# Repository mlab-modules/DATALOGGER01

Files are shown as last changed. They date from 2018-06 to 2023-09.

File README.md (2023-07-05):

# DATALOGGER01 - MLAB's Versatile processor module

The DATALOGGER01 is a versatile electronic module designed by MLAB, containing an ATmega1284p processor. The module is programmable in the Arduino IDE and compatible with a variety of development environments and programming languages.

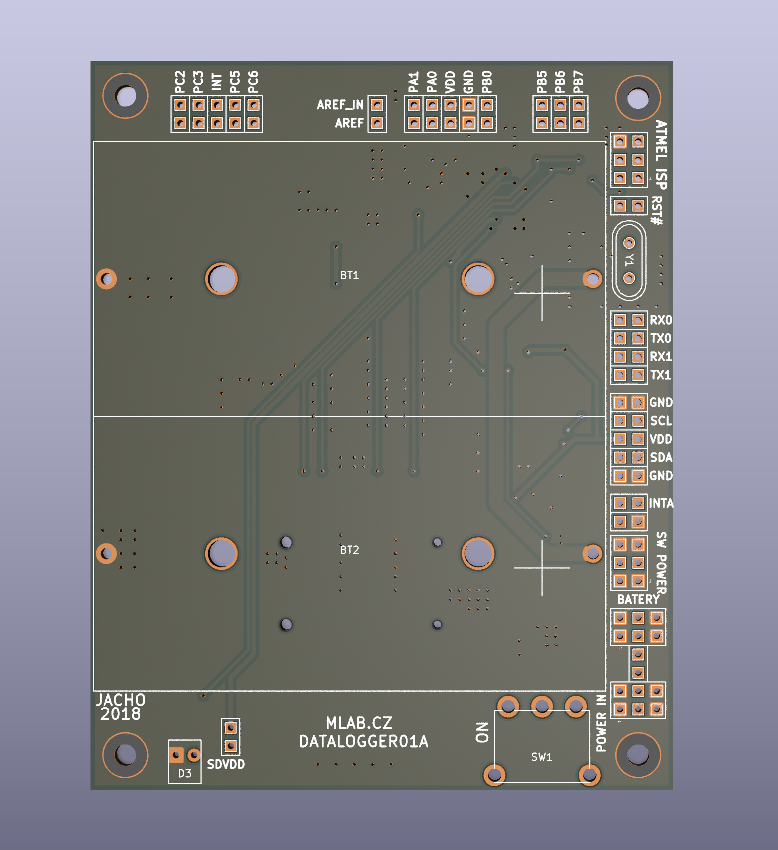
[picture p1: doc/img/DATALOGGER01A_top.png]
DATALOGGER01A
 

One of the significant features of this module is an SD card slot, a convenient provision for data logging from the processor. With a built-in battery holder, the module ensures uninterrupted operation without reliance on an external power supply.

The DATALOGGER01 exhibits a range of applications, thanks to its I2C, UART, ADC input, and GPIO pins. Additionally, it's furnished with a power switch to effectively manage power consumption of connected devices.

Setting it apart, the module includes an EEPROM AT23CS64, containing a unique serial number to distinguish logs from different DATALOGGER01-based devices. Moreover, it comprises a PCF85263 RTC circuit, with the option to connect a backup battery.

## Key Features:
- **Processor:** [ATmega1284p](https://en.wikipedia.org/wiki/Atmel_AVR#ATmega)
- **Interoperability:** Compatibility with Arduino and supports a range of other development platforms and programming languages.
- **Data Logging:** An SD Card Slot for extensive data storage.
- **Power Management:** Self-sufficient with an integrated battery holder.
- **Connectivity Options:** Diverse interfacing options with I2C, UART, ADC input, and GPIO pins.
- **Energy Efficiency:** Onboard power switch for managing external devices' power consumption.
- **Unique Identification:** Inbuilt [EEPROM AT23CS64](https://www.mouser.com/datasheet/2/268/doc0180-1353557.pdf) with a unique serial number.
- **Real-Time Tracking:** Inclusion of a [PCF85263](https://www.nxp.com/docs/en/data-sheet/PCF85263A.pdf) RTC circuit with backup battery connectivity.

## Potential Use Cases:
- **Data Collection:** Can collect, store, and analyze data from various sensors and devices.
- **Remote Monitoring:** Can be incorporated into IoT systems for remote data collection and monitoring.
- **Autonomous Systems:** Suitable for devices needing independent functioning.
- **Space Research:** Applicable as data loggers and locator devices for stratospheric balloons.

## In Action:
- The DATALOGGER01 module has proven its efficacy in:
   - **[GEODOS01](https://www.ust.cz/UST-dosimeters/GEODOS/)**: A fully autonomous scintillation detector incorporating LoRa IoT, operating without human intervention.
   - **FÍK stratospherics balloons Avionics**: DATALOGGER1 played a important role as a data logger and locator in the stratospheric balloons' avionics organized by [ODZ ÚJF](http://www.ujf.cas.cz/cs/oddeleni/oddeleni-dozimetrie-zareni/vyzkum/lety-fik/).

## Schematics



## Useful Links:
- [ATmega1284p](https://en.wikipedia.org/wiki/Atmel_AVR#ATmega) - Wikipedia
- [ARDUINO Programming Environment](https://www.arduino.cc/) - Official Arduino Site
- [EEPROM AT23CS64](https://www.mouser.com/datasheet/2/268/doc0180-1353557.pdf) - Mouser Electronics
- [PCF85263](https://www.nxp.com/docs/en/data-sheet/PCF85263A.pdf) - NXP Semiconductors

Discover the potential of DATALOGGER01 module and utilize it for your projects!

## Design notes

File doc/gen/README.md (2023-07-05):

# PCB

Board size: 80.77x101.09 mm (3.18x3.98 inches)

- This is the size of the rectangle that contains the board
- Thickness: 1.6 mm (63 mils)
- Material: FR4
- Finish: HAL
- Layers: 2
- Copper thickness: 35 µm

Solder mask: TOP / BOTTOM

- Color: Green

Silk screen: TOP / BOTTOM

- Color: White

# Important sizes

Clearance: 0.2 mm (8 mils)

Track width: 0.25 mm (10 mils)

- By design rules: 0.2 mm (8 mils)

Drill: 0.35 mm (14 mils)

- Vias: 0.5 mm (20 mils) [Design: 0.5 mm (20 mils)]
- Pads: 0.35 mm (14 mils)
- The above values are real drill sizes, they add 0.1 mm (4 mils) to plated holes (PTH)

Via: 0.8/0.4 mm (31/16 mils)

- By design rules: 0.8/0.4 mm (31/16 mils)
- Micro via: yes [0.2/0.1 mm (8/4 mils)]
- Buried/blind via: yes
- Total: 220 (thru: 220 buried/blind: 0 micro: 0)

Outer Annular Ring: 0.13 mm (5 mils)

- By design rules: 0.13 mm (5 mils)

Eurocircuits class: 6C
- Using min drill 0.35 mm for an OAR of 0.13 mm

# General stats

Components count: (SMD/THT)

- Top: 0/40 (THT)
- Bottom: 47/3 (SMD + THT)

Defined tracks:

- 0.25 mm (10 mils)
- 0.3 mm (12 mils)
- 0.4 mm (16 mils)
- 0.5 mm (20 mils)
- 0.6 mm (24 mils)
- 1.0 mm (39 mils)
- 2.0 mm (79 mils)

Used tracks:

- 0.25 mm (10 mils) (57) defined: yes
- 0.3 mm (12 mils) (233) defined: yes
- 0.4 mm (16 mils) (363) defined: yes
- 0.6 mm (24 mils) (67) defined: yes
- 2.0 mm (79 mils) (38) defined: yes

Defined vias:

- 0.8/0.4 mm (31/16 mils)

Used vias:

- 0.8/0.4 mm (31/16 mils) (Count: 220, Aspect: 2.0 A) defined: yes

Holes (excluding vias):

- 0.25 mm (10 mils) (2)
- 0.8 mm (32 mils) (2)
- 0.89 mm (35 mils) (80)
- 0.9 mm (35 mils) (2)
- 1.1 mm (43 mils) (2)
- 1.6 mm (63 mils) (6)
- 1.85 mm (73 mils) (5)
- 3.0 mm (118 mils) (3)
- 3.8 mm (150 mils) (4)

Oval holes:

Drill tools (including vias and computing adjusts and rounding):

- 0.35 mm (14 mils) (2)
- 0.5 mm (20 mils) (220)
- 0.9 mm (35 mils) (2)
- 1.0 mm (39 mils) (82)
- 1.1 mm (43 mils) (2)
- 1.6 mm (63 mils) (2)
- 1.7 mm (67 mils) (4)
- 1.95 mm (77 mils) (5)
- 3.1 mm (122 mils) (3)
- 3.8 mm (150 mils) (4)

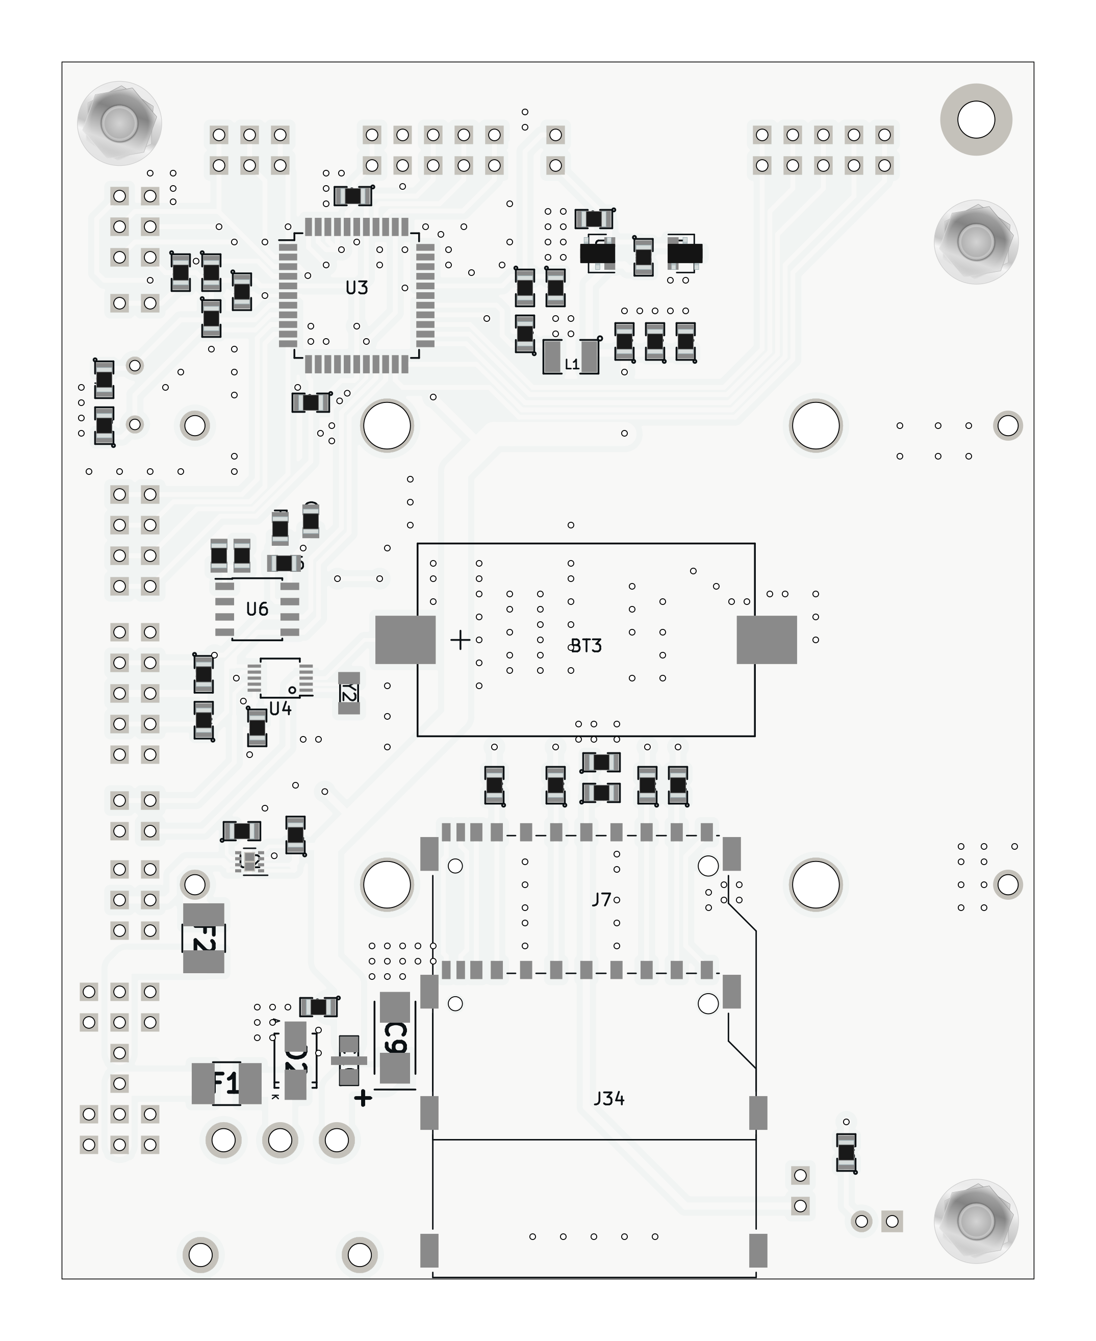
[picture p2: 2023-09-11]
doc/gen/img/DATALOGGER01-bottom.png

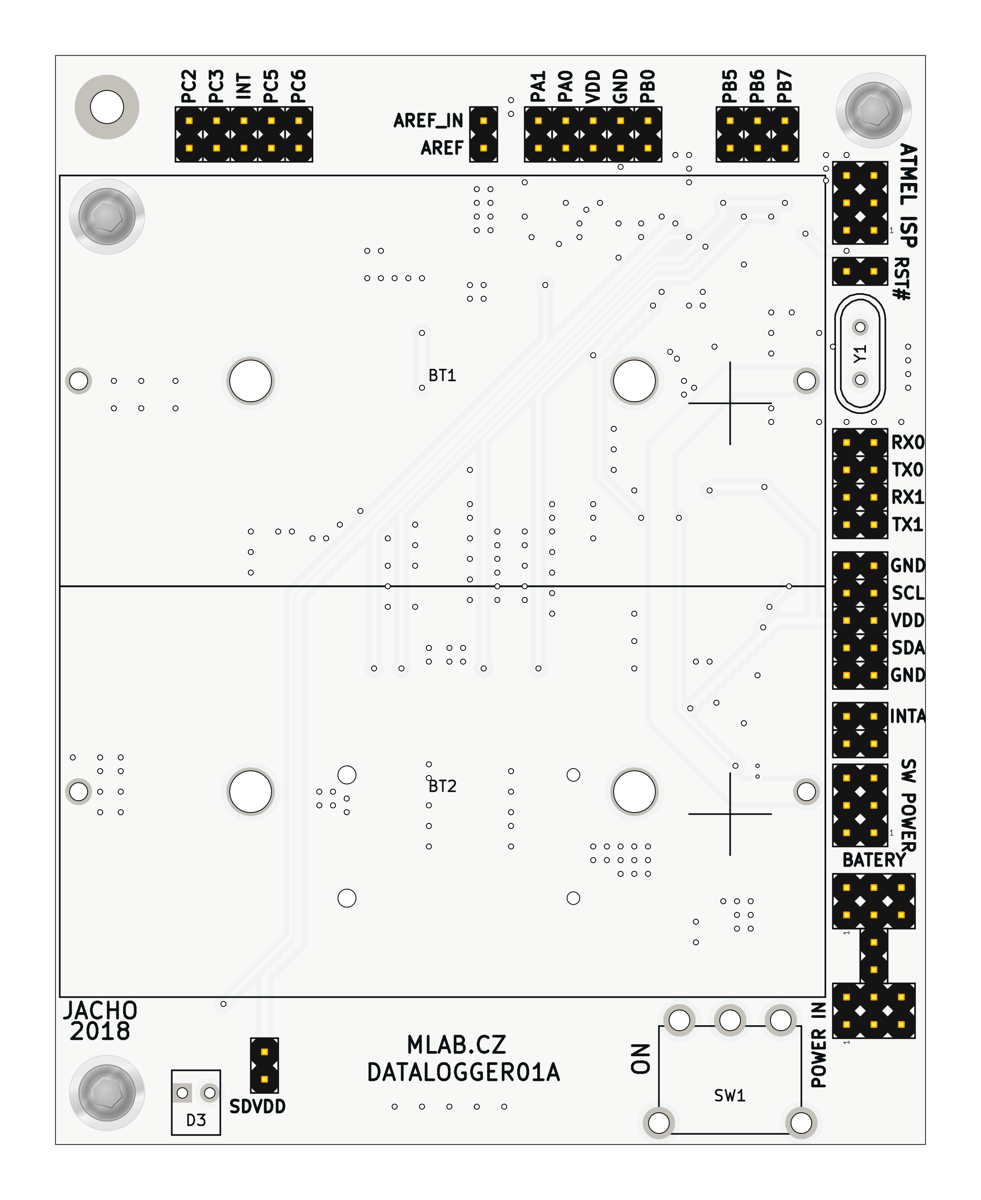
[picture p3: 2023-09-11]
doc/gen/img/DATALOGGER01-top.png

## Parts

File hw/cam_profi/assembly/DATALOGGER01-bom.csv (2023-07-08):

Component | Description | Part | References | Value | Footprint | Quantity Per PCB | Datasheet | ust_id
1 |  | Battery_Cell-device | BT1BT2 | BX0037 | BX0037 | 2 |  | 5c70984412875079b91f87ed
2 |  | Battery_Cell-device | BT3 | Battery_Cell-device | CH28-2032 | 1 |  | 5c70984412875079b91f87ec
3 |  | C-device | C5C8 | 15pF | SMD-0805 | 2 |  | 5c70984712875079b91f8b32
4 |  | C-device | C12 | 1nF | SMD-0805 | 1 |  | 5c70984712875079b91f8b45
5 |  | C-device | C1C2C3C4C6C13C15C17C18C19C20C21C22 | 100nF | SMD-0805 | 13 |  | 5c70984712875079b91f8b4c
6 |  | C-device | C7 | 1uF | SMD-0805 | 1 |  | 5c70984712875079b91f8b50
7 |  | C-device | C16 | 4u7 | SMD-0805 | 1 |  | 5c70984712875079b91f8b52
8 |  | C-device | C11C14 | 10uF | SMD-0805 | 2 |  | 5c70984812875079b91f8bbd
9 |  | CP-device | C9 | 47uF | TantalC_SizeC_Reflow | 1 |  | 5c70984412875079b91f8867
10 |  | EMI_Filter_C-device | C10 | EMI_Filter_C | FIR1 | 1 | http://www.murata.com/~/media/webrenewal/support/library/catalog/products/emc/emifil/c31e.ashx?la=en-gb
11 |  | LED-device | D3 | HLMP-K150+FIX-LED-313 | FIX-LED-313 | 1 |  | 5c70984712875079b91f8b67
12 |  | D-device | D2 | M4 | SMA_Standard | 1 |  | 5c70984512875079b91f88ac
13 |  | Polyfuse-device | F1F2 | 750mA | 1812 | 2 |  | 5c70984512875079b91f88d2
14 |  | HEADER_2x01-MLAB_HEADER | J9J11J21J32 | HEADER_2x01 | Straight_2x01 | 4
15 |  | HEADER_2x01_PARALLEL-MLAB_HEADER | J1J2J3J4J5J8J12J13J14J15J16J17J18J19J20J22J23J24J25J26J27J28J29J30 | HEADER_2x01_PARALLEL | Straight_2x01 | 24
16 |  | HEADER_2x03-MLAB_HEADER | J31 | HEADER_2x03 | Straight_2x03 | 1
17 |  | HEADER_2x03_PARALLEL-MLAB_HEADER | J6J10J33 | HEADER_2x03_PARALLEL | Straight_2x03 | 3
18 |  | SD_Card-Connector | J7 | MCC-SD | SD_TE_2041021 | 1 | http://portal.fciconnect.com/Comergent//fci/drawing/10067847.pdf | 5c70984412875079b91f87f2
19 |  | SD_Card-Connector | J34 | MCC-SD (kouka z modulu) | MCC-SD | 1 | http://portal.fciconnect.com/Comergent//fci/drawing/10067847.pdf
20 |  | L-device | L1 | 10uH - LQH32CN100K23L | SMD-1210 | 1 |  | 5c70984412875079b91f87ff
21 |  | R-device | R12R15 | 0R | SMD-0805 | 2 |  | 5c70984512875079b91f896b
22 |  | R-device | R1R2R3R4 | 100 | SMD-0805 | 4 |  | 5c70984512875079b91f8977
23 |  | R-device | R10 | 2k2 | SMD-0805 | 1 |  | 5c70984612875079b91f8990
24 |  | R-device | R5 | 4k7 | SMD-0805 | 1 |  | 5c70984612875079b91f8995
25 |  | R-device | R6R7R9 | 10k | SMD-0805 | 3 |  | 5c70984612875079b91f899f
26 |  | R-device | R8R11R16 | - | SMD-0805 | 3
27 | Single Pole Single Throw (SPST) switch | SW_SPST | SW1 | 5MS1S102AM6QE | 5MS1S102AM6QE | 1 | ~ | 5c70984712875079b91f8b66
28 | I2C Serial EEPROM, 64Kb (8192x8) with Unique Serial Number, SO8 | AT24CS64-SSHM | U6 | AT24CS64-SSHM | SOIC-8_3.9x4.9mm_P1.27mm | 1 | http://ww1.microchip.com/downloads/en/DeviceDoc/Atmel-8870-SEEPROM-AT24CS64-Datasheet.pdf | 5c70984712875079b91f8b99
29 |  | ATMEGA1284P-AU-atmel | U3 | ATMEGA1284P-AU | TQFP-44_10x10mm_P0.8mm | 1 | http://www.atmel.com/Images/Atmel-8272-8-bit-AVR-microcontroller-ATmega164A_PA-324A_PA-644A_PA-1284_P_datasheet.pdf | 5c70984412875079b91f888e
30 |  | ISL21070CIH320Z-TK-references | U1 | ISL21080CIH320Z-TK | SOT-23 | 1 | http://www.intersil.com/content/dam/Intersil/documents/fn75/fn7599.pdf | 5c70984712875079b91f8b79
31 |  | LM4041CIM3-1.2-MLAB_D | U5 | LM4041CIM3-1.2(neosazovat) | SOT-23 | 1
32 |  | PCF85263A-MLAB_IO | U4 | PCF85263A | TSSOP-10_3x3mm_Pitch0.5mm | 1 |  | 5c70984612875079b91f8a0c
33 |  | TPS22965-Q1-MLAB_IO | U2 | TPS22965-Q1 | WSON-8-1EP_2x2mm_P0.5mm_EP0.9x1.6mm_ThermalVias | 1 |  | 5c70984712875079b91f8b78
34 | Two pin crystal | Crystal | Y1 | 16MHz | Crystal_HC49-U_Vertical | 1 | ~ | 5c70984712875079b91f8b10
35 |  | Crystal-device | Y2 | ABS07-120-32.768KHZ-T | ABS07 | 1 |  | 5c70984712875079b91f8b1b

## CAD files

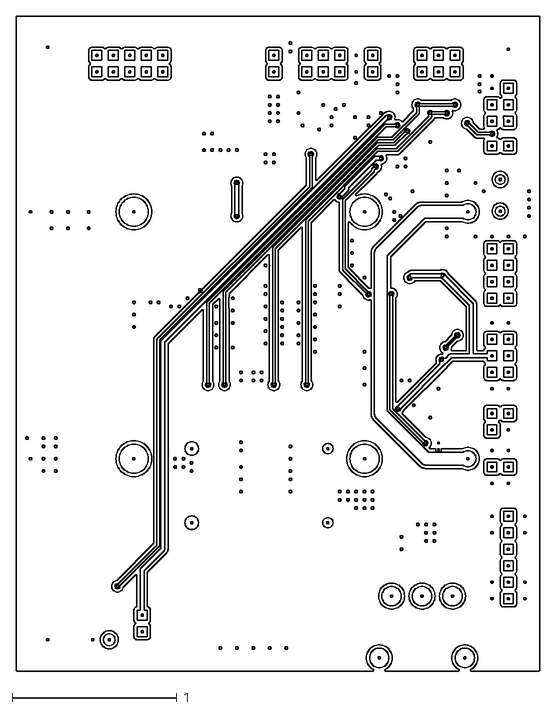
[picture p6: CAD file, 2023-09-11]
doc/gen/dxf/DATALOGGER01-F_Cu.dxf
3.18 x 3.98

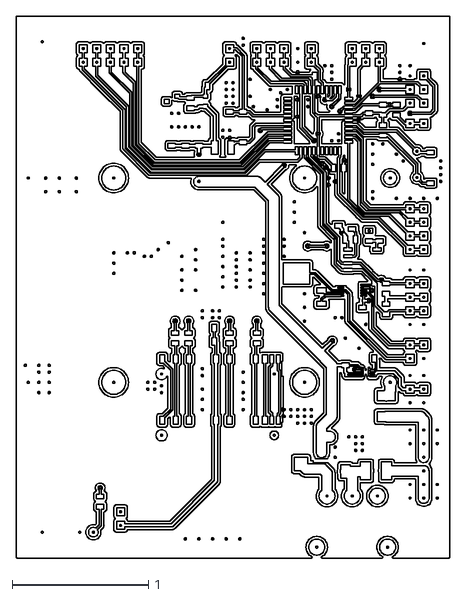
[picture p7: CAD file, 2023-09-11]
doc/gen/dxf/DATALOGGER01-B_Cu.dxf
3.18 x 3.98

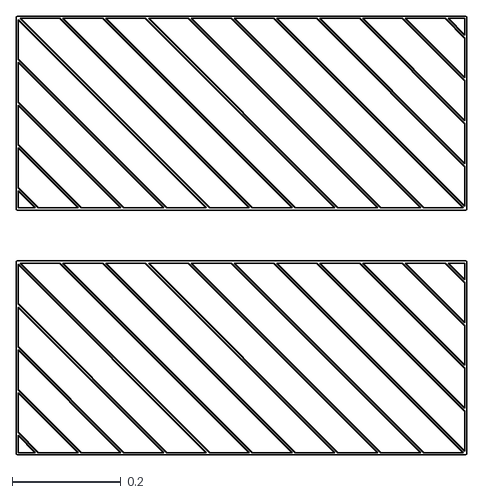
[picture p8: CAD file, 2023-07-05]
doc/gen/dxf/DATALOGGER01-User_Drawings.dxf
0.83 x 0.806

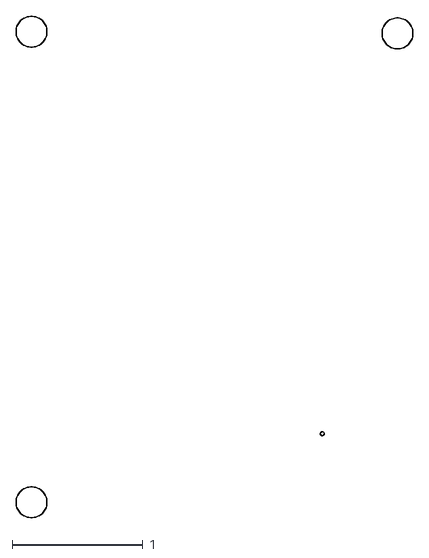
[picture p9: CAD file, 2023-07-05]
doc/gen/dxf/DATALOGGER01-B_Adhesive.dxf
3.04 x 3.84

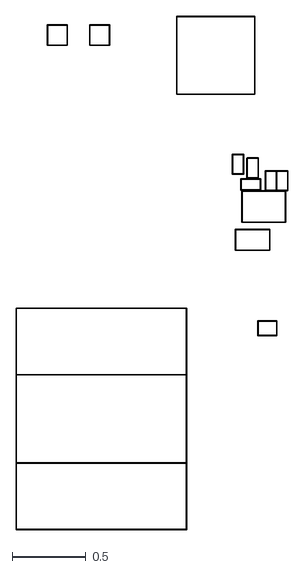
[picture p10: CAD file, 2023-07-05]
doc/gen/dxf/DATALOGGER01-B_Courtyard.dxf
1.84 x 3.48

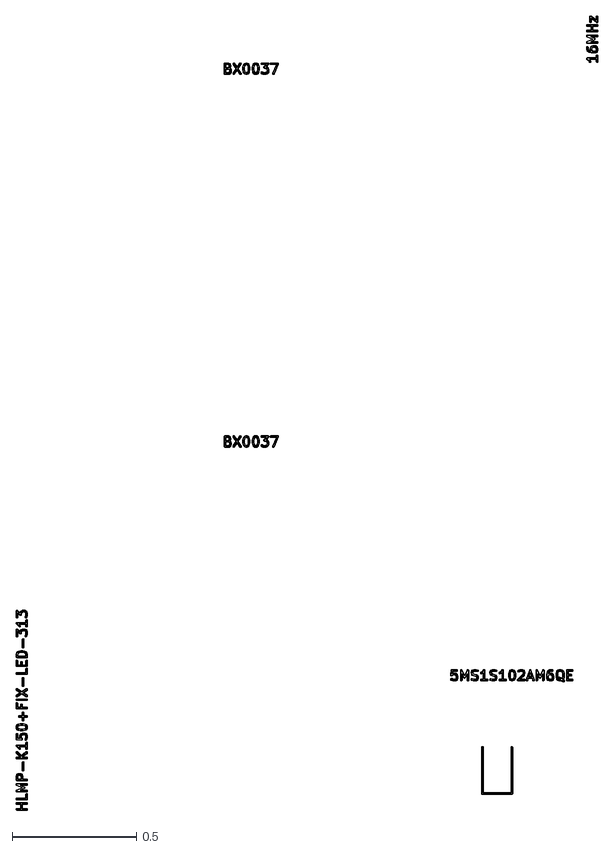
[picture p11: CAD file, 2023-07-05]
doc/gen/dxf/DATALOGGER01-F_Fab.dxf
2.34 x 3.19

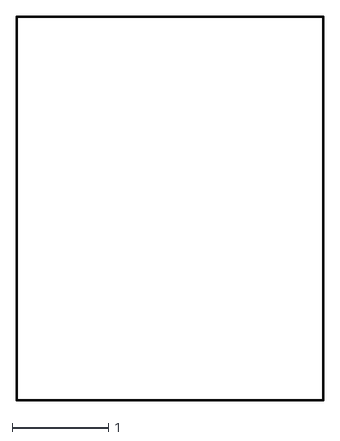
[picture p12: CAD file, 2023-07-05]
doc/gen/dxf/DATALOGGER01-Edge_Cuts.dxf
3.19 x 3.99

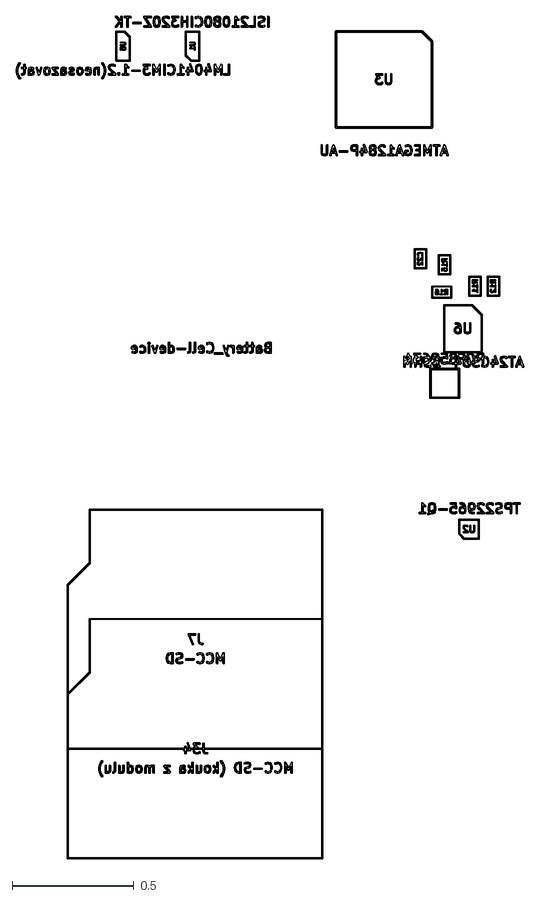
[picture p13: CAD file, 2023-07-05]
doc/gen/dxf/DATALOGGER01-B_Fab.dxf
2.09 x 3.47

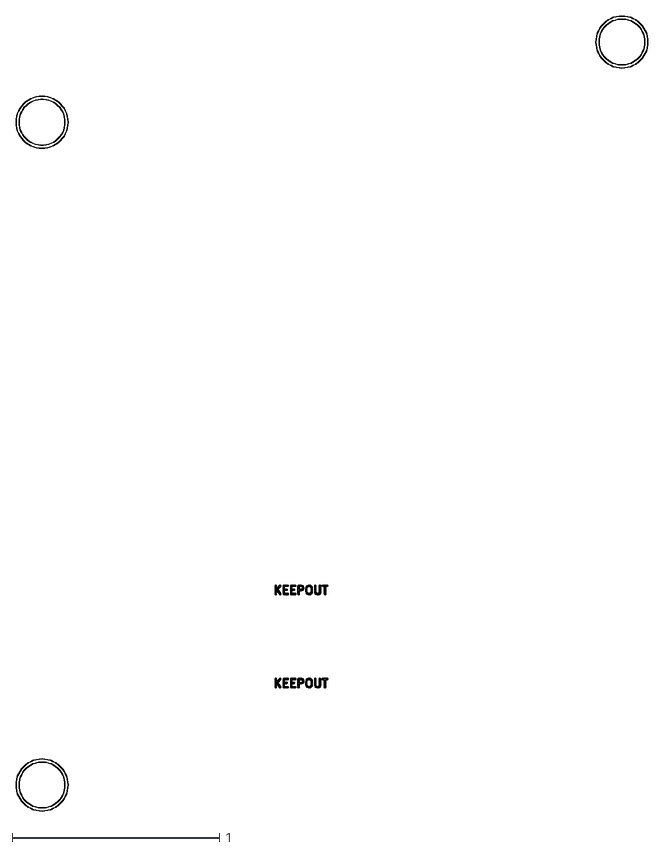
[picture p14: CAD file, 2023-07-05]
doc/gen/dxf/DATALOGGER01-User_Comments.dxf
3.05 x 3.84

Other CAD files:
doc/gen/dxf/DATALOGGER01-F_Courtyard.dxf
doc/gen/dxf/DATALOGGER01-Margin.dxf
doc/gen/dxf/DATALOGGER01-B_Mask.dxf
doc/gen/dxf/DATALOGGER01-B_Paste.dxf
doc/gen/dxf/DATALOGGER01-B_Silkscreen.dxf
doc/gen/dxf/DATALOGGER01-F_Mask.dxf
doc/gen/dxf/DATALOGGER01-F_Silkscreen.dxf

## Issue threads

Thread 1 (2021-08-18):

Hodnota kapacit u krystalu

kaklik, 2021-08-18:
Tam se vážně ke krystalu osazují kondenzátory 100nF?!

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

Domnívám se, že není možné aby to v takové konfiguraci fungovalo. Je to tak potřeba ve schématu opravit na správnou hodnotu.

Podle [datasheetu](http://ww1.microchip.com/downloads/en/DeviceDoc/Atmel-42719-ATmega1284P_Datasheet.pdf) v sekci 10.3. by zde měly být úplně jiné hodnoty kapacit.

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

kaklik, 2022-08-14:
Vypadá to, že tato záležitost je ve schématu nyní opravena.

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

Closed 2022-08-14.

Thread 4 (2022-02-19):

Future architecture of DATALOGGER board

kaklik, 2022-02-19:
There are multiple choices of better suitable ICs for the next DATALOGGER module version.

- [rp2040](https://www.raspberrypi.com/documentation/microcontrollers/rp2040.html)
- An standard ARM microcontroller like  STM microcontroller
- FPGA based like [PROGLOG](https://github.com/mlab-modules/PROGLOG01)

In every case the design requirements are

- Easy to write and recompile the firmware (with clear noticeable code mistakes).
   - The compilation should not depend of the compiler version
- External memory interface (Like SDcard or other memory type with [high-reliability](https://github.com/UniversalScientificTechnologies/SPACEDOS02/issues/8))

kaklik, 2022-04-03:
v případě použití RP2040 může být problém spotřeba, která je i v režimu sleep 0.39mA. Viz [datasheet strana 642](https://datasheets.raspberrypi.com/rp2040/rp2040-datasheet.pdf)

kaklik, 2022-09-03:
The current software framework used in datalogger is Arduino, which was selected based on widespread usage. Unfortunately, it has significant drawbacks in the reliability of compiled output.

Other variants to use are:

- https://tinygo.org/

kaklik, 2024-12-07:
Nejdůležitějším kritériem volby nové architektury (typu MCU) je zřejmě možnost komunikace s SDkartou přes SDIO.

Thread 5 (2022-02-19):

SDcard friendly filesystem

kaklik, 2022-02-19:
Aktuálně je pro vytváření záznamů na SDkartě používán souborový systém FAT, ten má mnoho nevýhod vyplývajících z toho, že byl navržen pro úplně jiné aplikace a za jiných podmínek.

@povik  našel [littlefs](https://github.com/littlefs-project/littlefs), který je naopak konstruován tak, aby většinu potíží s používáním kombinace FAT a SDkarta vyřešil.

Bohužel littlefs zřejmě nemá podporu pro Arduino kromě ESP32

Existují však různé [varianty littlefs i pro jiné typy pamětí, než FLASH](https://github.com/PaulStoffregen/LittleFS).

kaklik, 2022-04-03:
kromě ESP32 existuje [podpora ještě pro RP2040](https://github.com/khoih-prog/LittleFS_Mbed_RP2040).

kaklik, 2022-09-03:
Zjistil jsem že littlefs je zřejmě [implementovaný v TinyGo](https://github.com/tinygo-org/tinyfs/tree/release/littlefs).

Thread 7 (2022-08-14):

Powering voltage

kaklik, 2022-08-14:
V zařízení [CARDOS01](https://github.com/ODZ-UJF-AV-CR/CARDOS01) se ukázalo, že existují kusy u kterých se nerozeběhne MCU při napájení 3.3V.

Tato situace je konzistentní s [datasheetem](https://ww1.microchip.com/downloads/aemDocuments/documents/MCU08/ProductDocuments/DataSheets/ATmega164A_PA-324A_PA-644A_PA-1284_P_Data-Sheet-40002070B.pdf), který potvrzuje, že ATmega1384P má na 16MHz začít spolehlivě fungovat až od 3.78V.

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

**Toto zjištění má vliv na většinu zařízení, kde je DATALOGGER01A používán.**
FYI @kakl  @ChroustJan

kaklik, 2022-08-19:
Situaci může i napomáhat aktuální layout krystalu, který má velmi dlouhé přívody.

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

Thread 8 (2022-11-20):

Battery cell short-circuit

kaklik, 2022-11-20:
U [SAFT článků](https://www.tme.eu/cz/details/saft-ls33600/baterie/saft/ls-33600/) zapojených ve dvojici paralelně se stává, že se občas jeden z dvojice vyzkratuje.
Tím se stane, že vybije i druhý. Tato událost pak zkrátí použitelnou dobu logování přístroje.

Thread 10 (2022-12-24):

Balloon tracker application

kaklik, 2022-12-24:
Madul datalogeru byl již několikrát použit na balonových letech v kombinaci s moduly [GPS02](https://github.com/mlab-modules/GPS02), [ALTIMET](https://github.com/mlab-modules/ALTIMET01) a [ISM02B](https://github.com/mlab-modules/ISM02).

Ukazuje se, že tato sestava je velmi častá kombinace modulů, která je použita opakovaně. (Např. i v zařízení [GEODOS](https://github.com/UniversalScientificTechnologies/GEODOS01)).  Dává tak smysl funkce těchto modulů sloučit, nebo upravit tak, aby výsledek byl snadněji použitelný a ještě více spolehlivý. Zařízení by tak bylo doplňkem k systému [TF-ATMON](https://www.thunderfly.cz/tf-atmon.html), který by stále sloužil jako hlavní kanál pro přenos telemetrie přes [433 MHz SIK modem](https://github.com/ThunderFly-aerospace/TFSIK01). Nové zařízení by pak mělo primární funkci sekundárního trackeru sloužícímu ke spolehlivému dohledání. Kromě těchto dvou vysílačů by byl stále zachován ještě záložní CW morse maják s nízkým výkonem na 433MHz a samostatným napájením, který umožní dohledání při úplném selhání předchozích dvou systémů, nebo při výpadku navigace.

Nový DATALOGGER02A by tak měl splňovat tyto požadavky:

- Asi stále zachovat architekturu založenou na ATmega (pokud stále jdou sehnat) i když k ní existuje mnoho výhrad #4
- Zachovat montáž na MLAB desku (aby to šlo snadno používat při experimentech s dalšími moduly)
- Snížit rozměry oproti původnímu velkému PCB DATALOGGER01
- Předpokládat napájení z jednoho článku velikosti 18650 (48g) místo původní dvojice LS33600 (90g každá), tohle rovnou vyřeší problém #8, úplně nejlepší by bylo sem přidat i gauge z modulu [LION1CELL](https://github.com/mlab-modules/LION1CELL01). Zde je ale nepříjemné, že moderní je zařízení nabíjet přes USB-C. Tudíž by se hodil USB-C nabíjecí konektor. Není pak jednoznačné jestli napájení nadále nenechat na modulu LION1CELL ale pouze od něj udělat novou verzi s USB-C konektorem.
- Jako zdroj polohy předpokládat připojení [TFGPS](https://github.com/ThunderFly-aerospace/TFGPS01), která bude připojená přes _Autopilot GPS&SAFETY_ konektor
- Napájení pro GPS mít možnost elekronicky vypnout z firmware
- Přidat teploměr a tlakoměr na jeden PCB.  Původně to bylo vyřešeno modulem [ALTIMET01](https://github.com/mlab-modules/ALTIMET01), který ale obsahuje obvod, který se nedá koupit. To znamená, že je potřeba najít nový barometr na I2C, který zároveň bude měřit ve 30km.
- Přidat celý [LoRa modul](https://github.com/mlab-modules/ISM02)
- Přidat FRAM pro logování malých dat.

kaklik, 2022-12-26:
Vhodným řešením dilema s napájením by zřejmě bylo použití [superkondenzátoru, jako UPS](https://www.analog.com/en/technical-articles/supercap-backup-circuit-provides-reliable-uninterrupted-power.html). Měli bychom mít skladem [50F variantu](https://www.tme.eu/cz/details/ds5u506m18040bb/superkondenzatory/samwha/) v dostatečném množství.

Takové řešení ale potřebuje IC, který vyřeší přechod z externího napájení 3.3V na backup napájení z kondenzátoru, který má maximálně 2.7V. Obvody, které jsem našel jsou například:

- https://www.analog.com/en/products/ltc4041.html

Je jich ale více.

kaklik, 2024-09-29:
Na základě aktuálních zkušeností z GEODOSu a dalších zařízení to vypadá, že  integrace modulu [LION1CELL](https://github.com/mlab-modules/LION1CELL01) do DATALOGGER02 je vyloženě nežádoucí. Protože neumožňuje pak datalogger provozovat v podmínkách mrazu.  Místo toho se lépe osvědčil [SOLARMINIBAT01](https://github.com/mlab-modules/SOLARMINIBAT01). Protože zde ale existuje více variant externích zdrojů, tak by zřejmě bylo lepší napájení oddělit a v modulu DATALOGGER02 nechat pouze zálozní kondenzátor, který umožní kritické akce při výpadku externího napájení (Odeslání poslední zprávy, uzavření souboru na SDkartě a podobně).

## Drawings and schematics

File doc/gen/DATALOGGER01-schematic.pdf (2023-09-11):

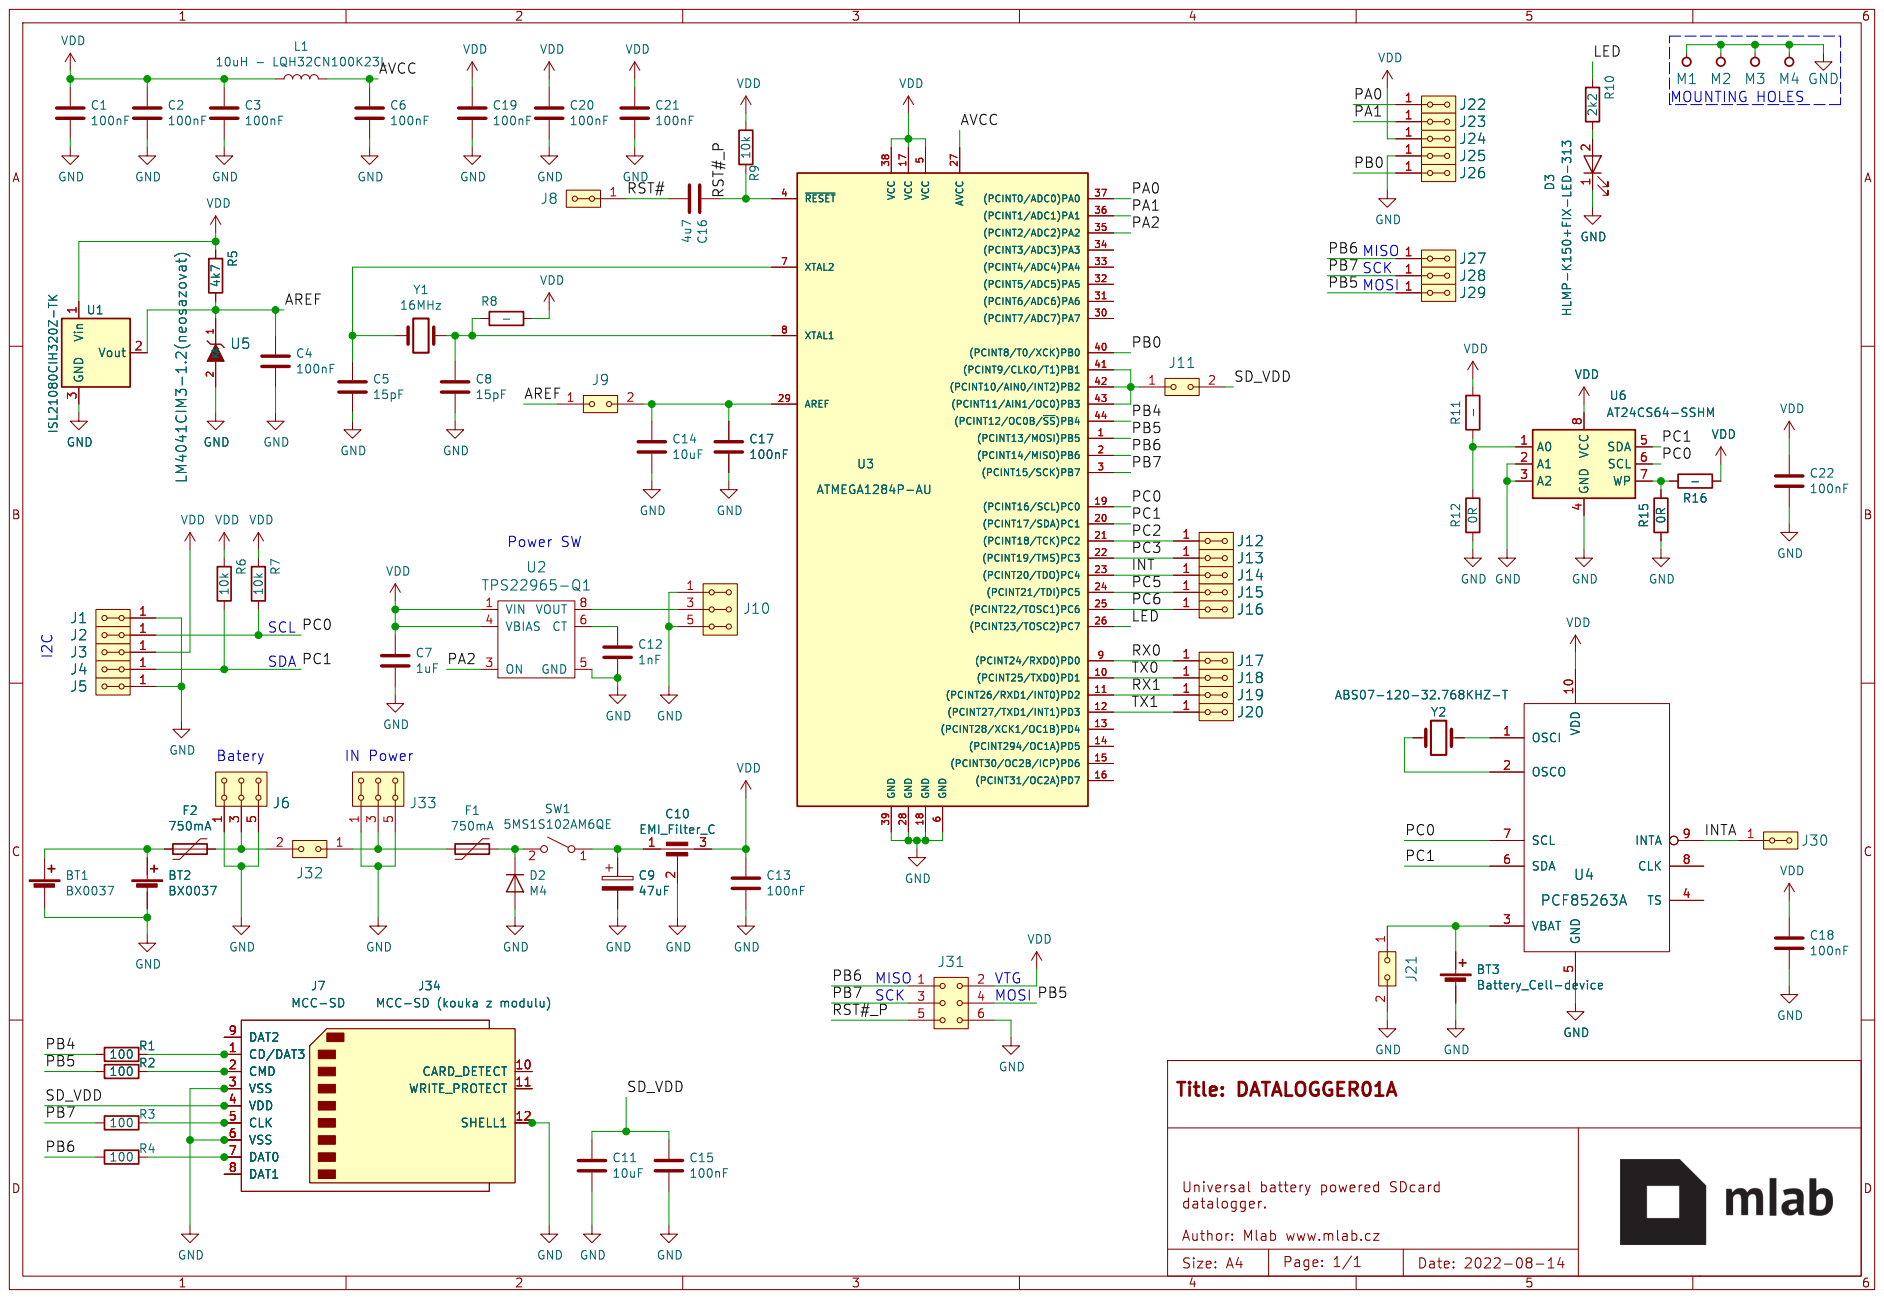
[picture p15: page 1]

3 U1 ISL21080CIH320Z-TK GND GND GND

4 SDA 5 SCL 6 WP 7 VCC
BT3 Battery_Cell-deviceVDD

1 2 J21 OSCI 1 VDD 10 OSCO 2 VBAT 3 TS 4 GND
Y2 ABS07-120-32.768KHZ-T BT3 Battery_Cell-device GNDU4 PCF85263A

J34 MCC-SD (kouka z modulu) 1

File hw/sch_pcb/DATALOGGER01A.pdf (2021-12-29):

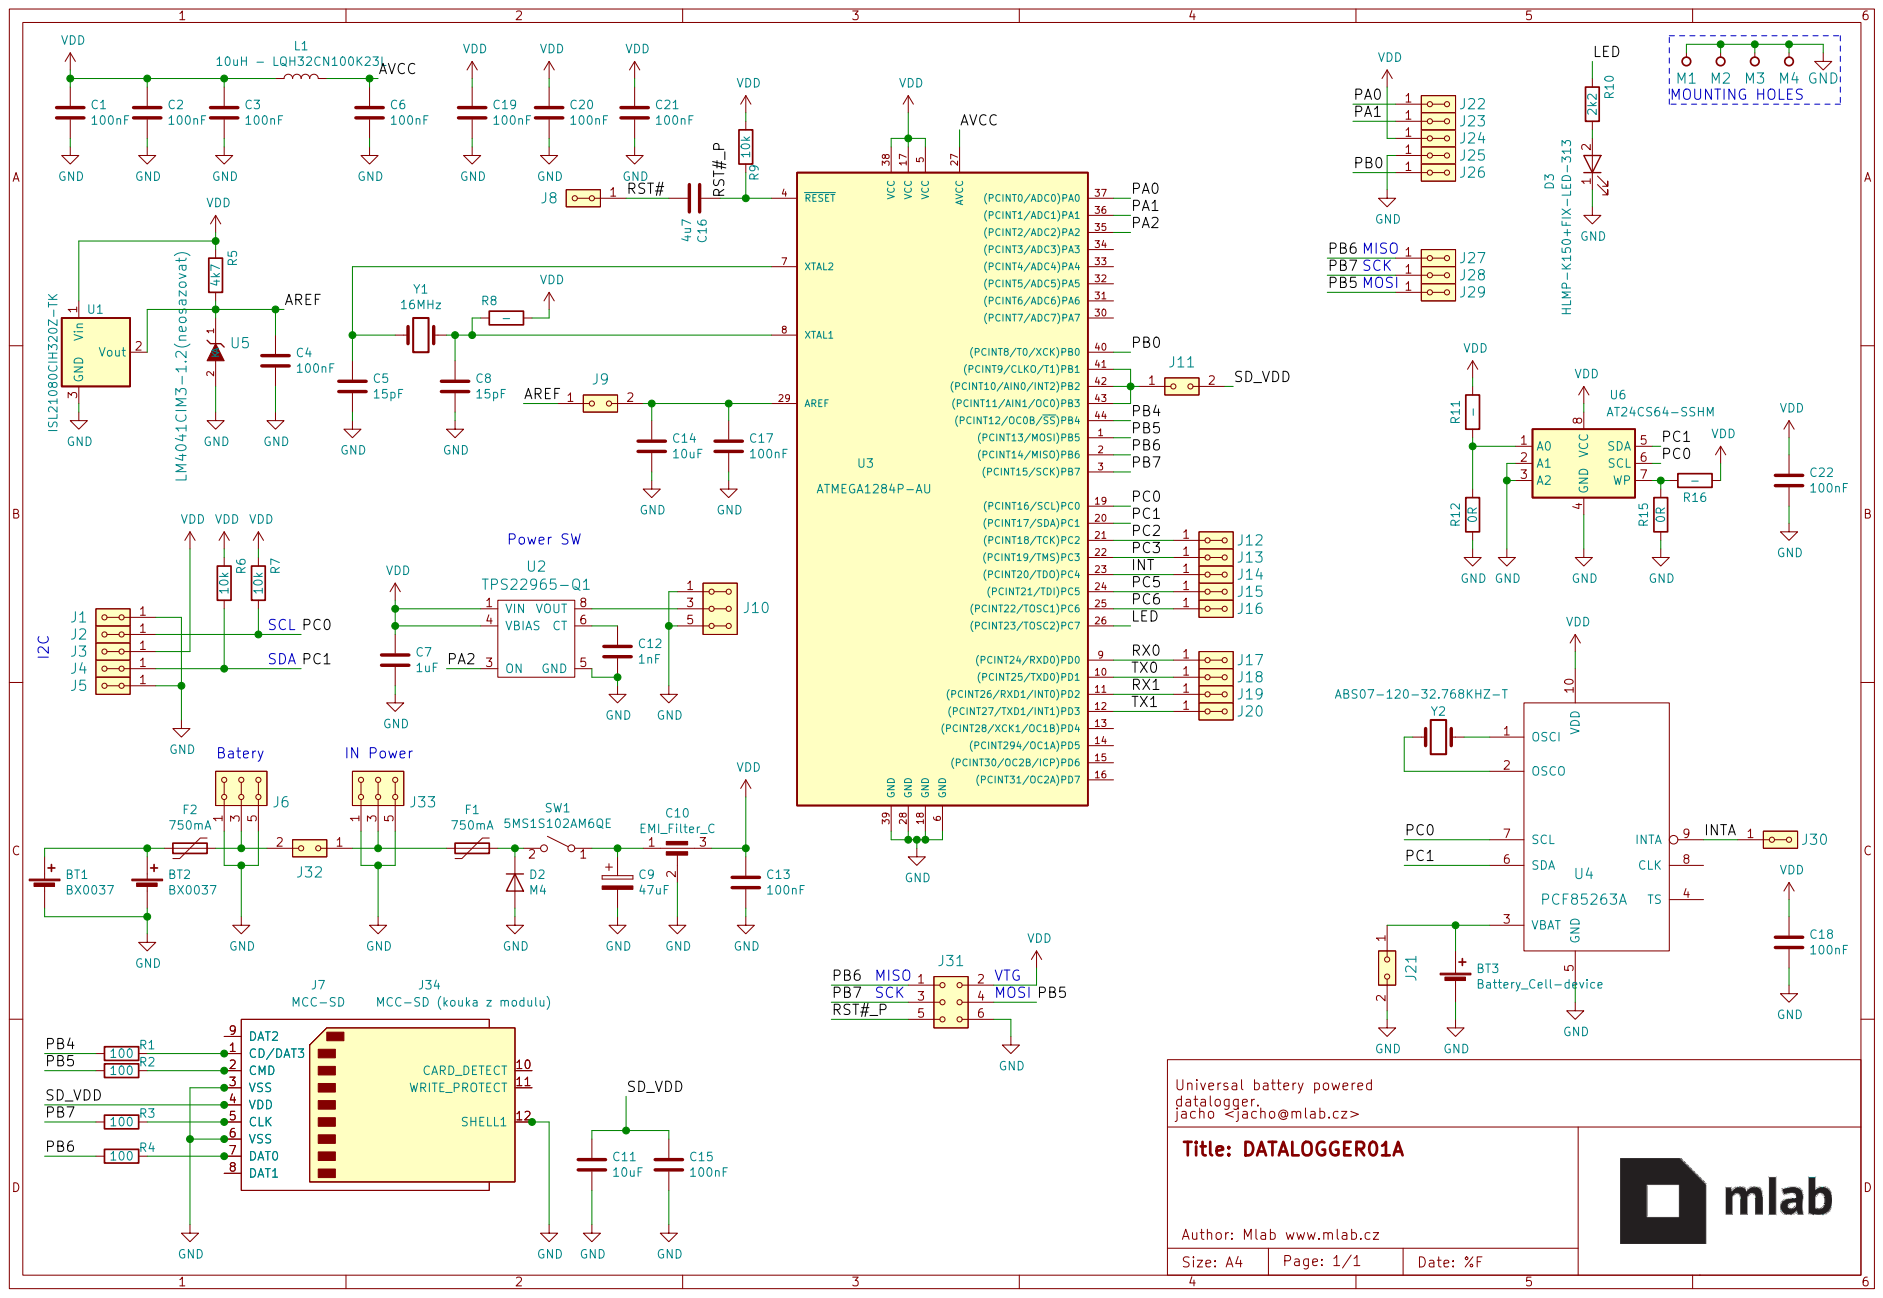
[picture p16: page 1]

1 2 D3 HLMP-K150+FIX-LED-313 VDD

4 SDA 5 SCL 6 WP 7 VCC

jacho <jacho@mlab.cz> GND

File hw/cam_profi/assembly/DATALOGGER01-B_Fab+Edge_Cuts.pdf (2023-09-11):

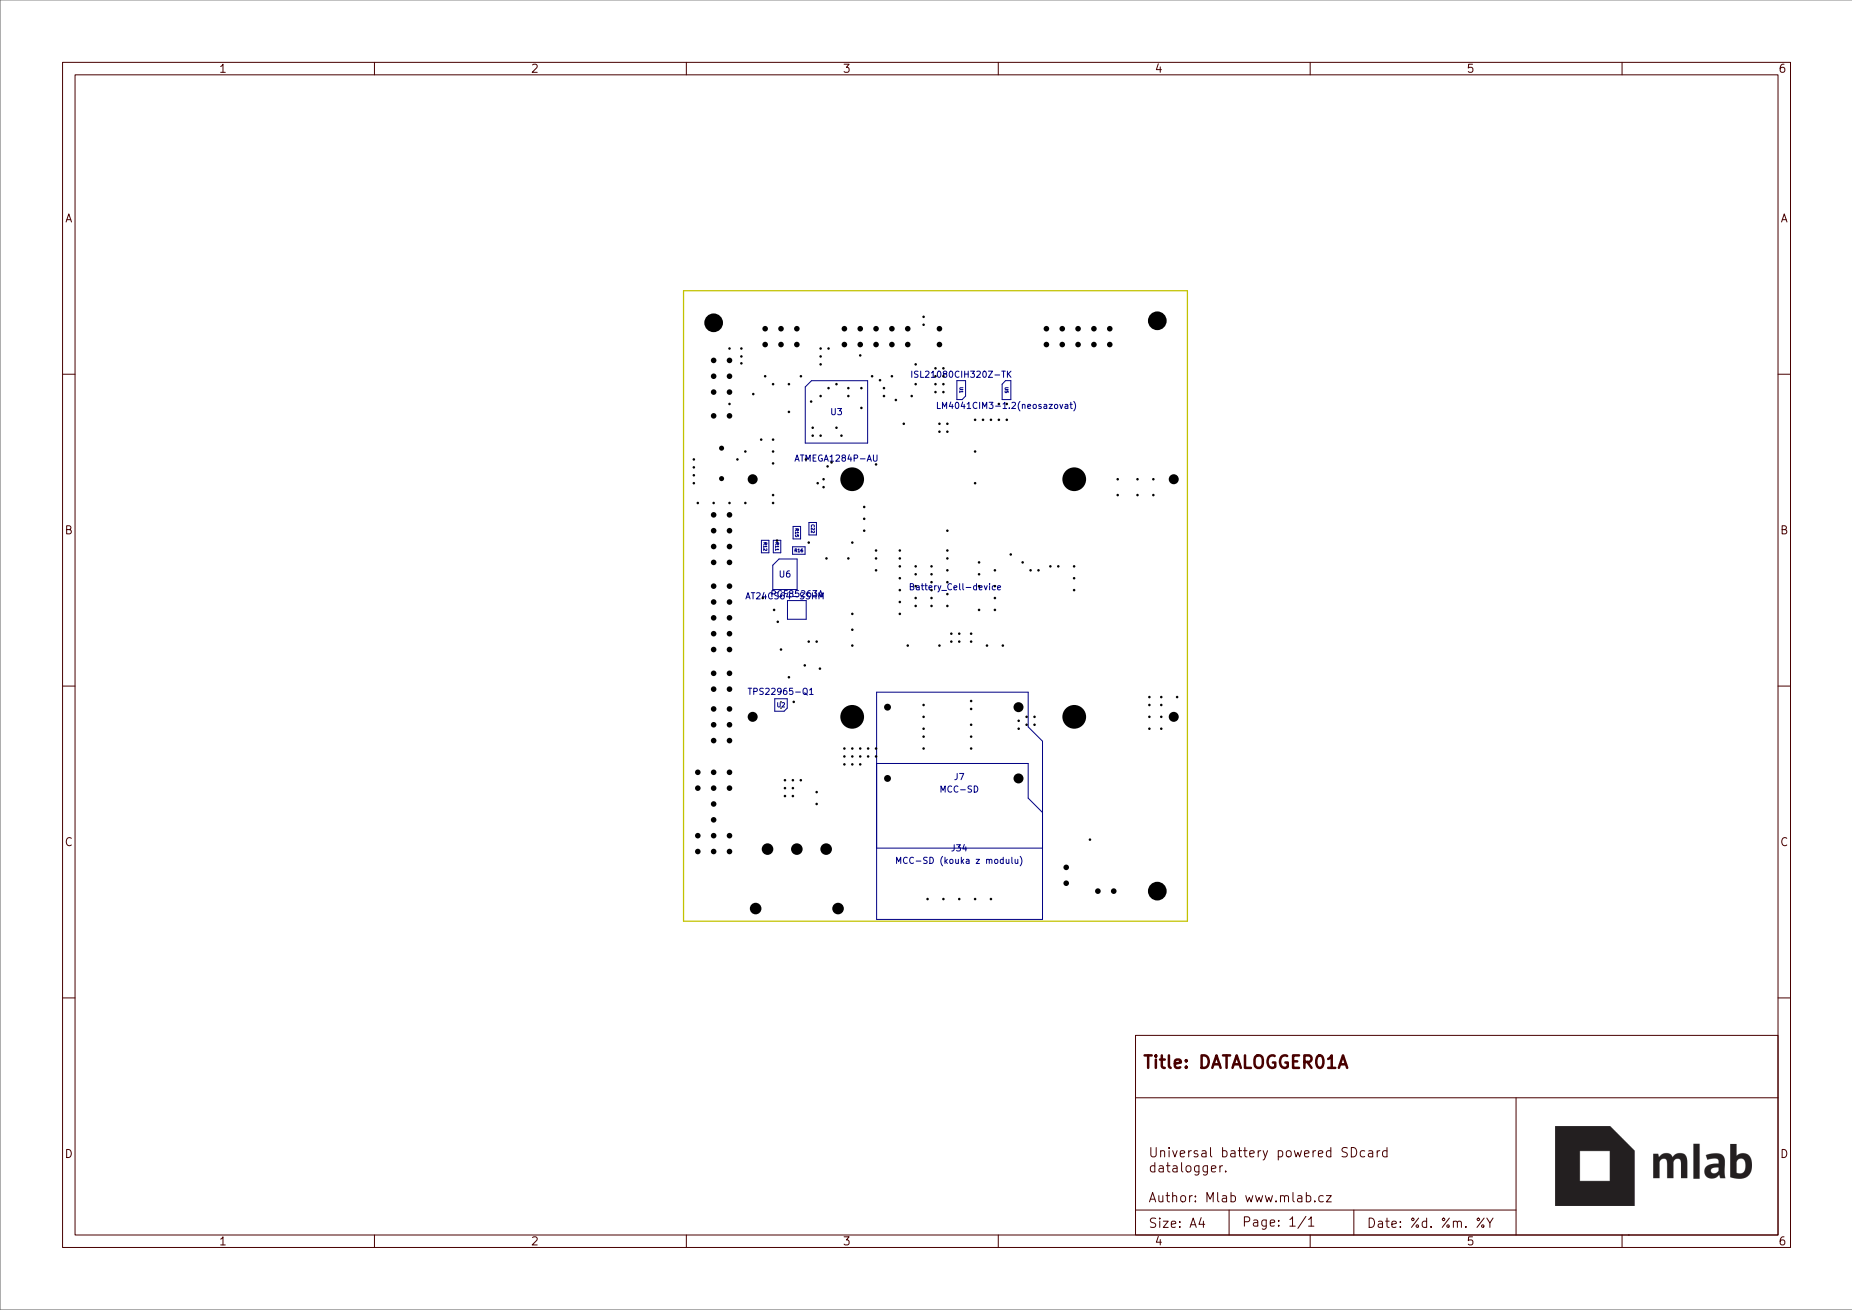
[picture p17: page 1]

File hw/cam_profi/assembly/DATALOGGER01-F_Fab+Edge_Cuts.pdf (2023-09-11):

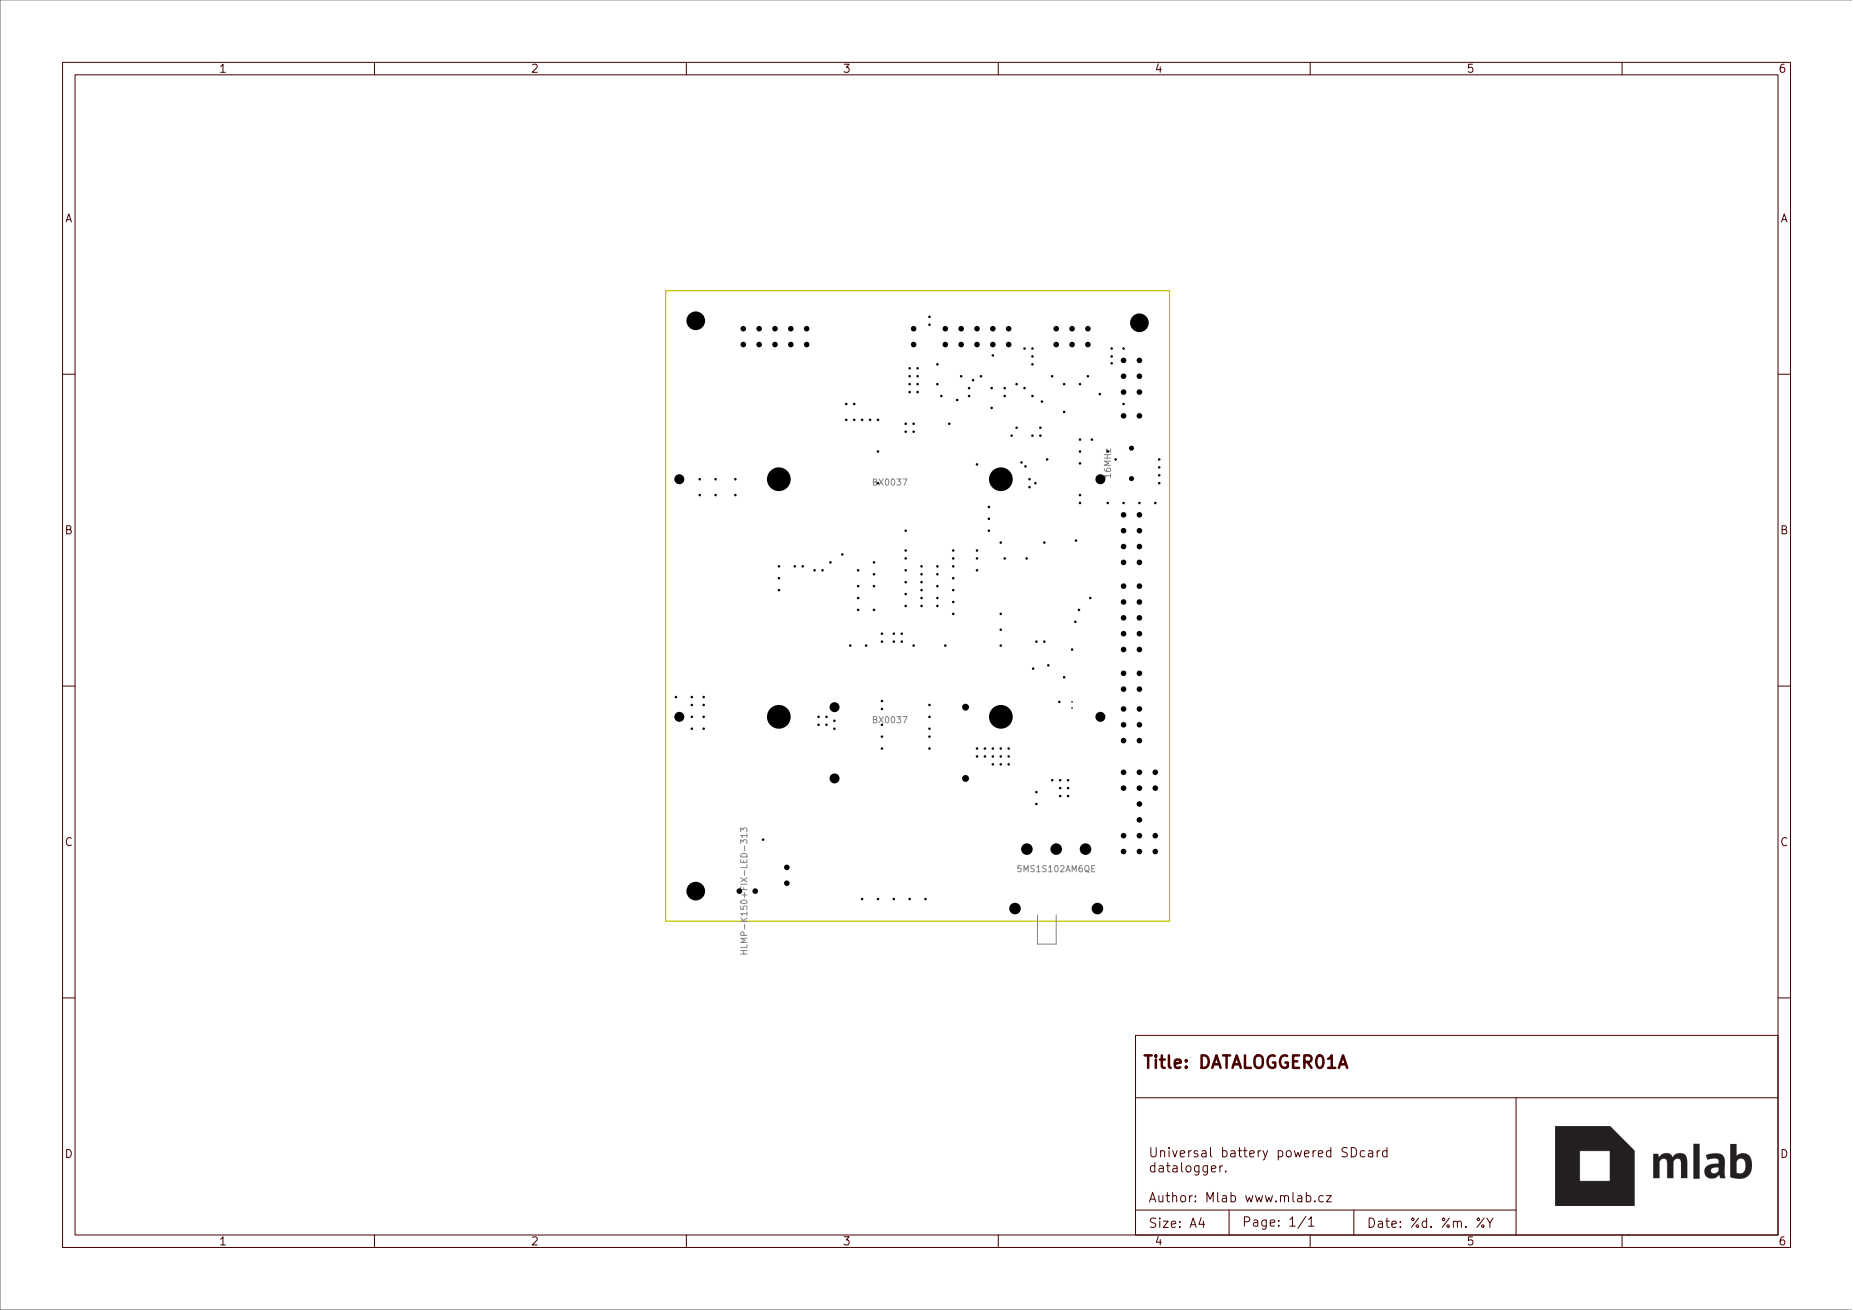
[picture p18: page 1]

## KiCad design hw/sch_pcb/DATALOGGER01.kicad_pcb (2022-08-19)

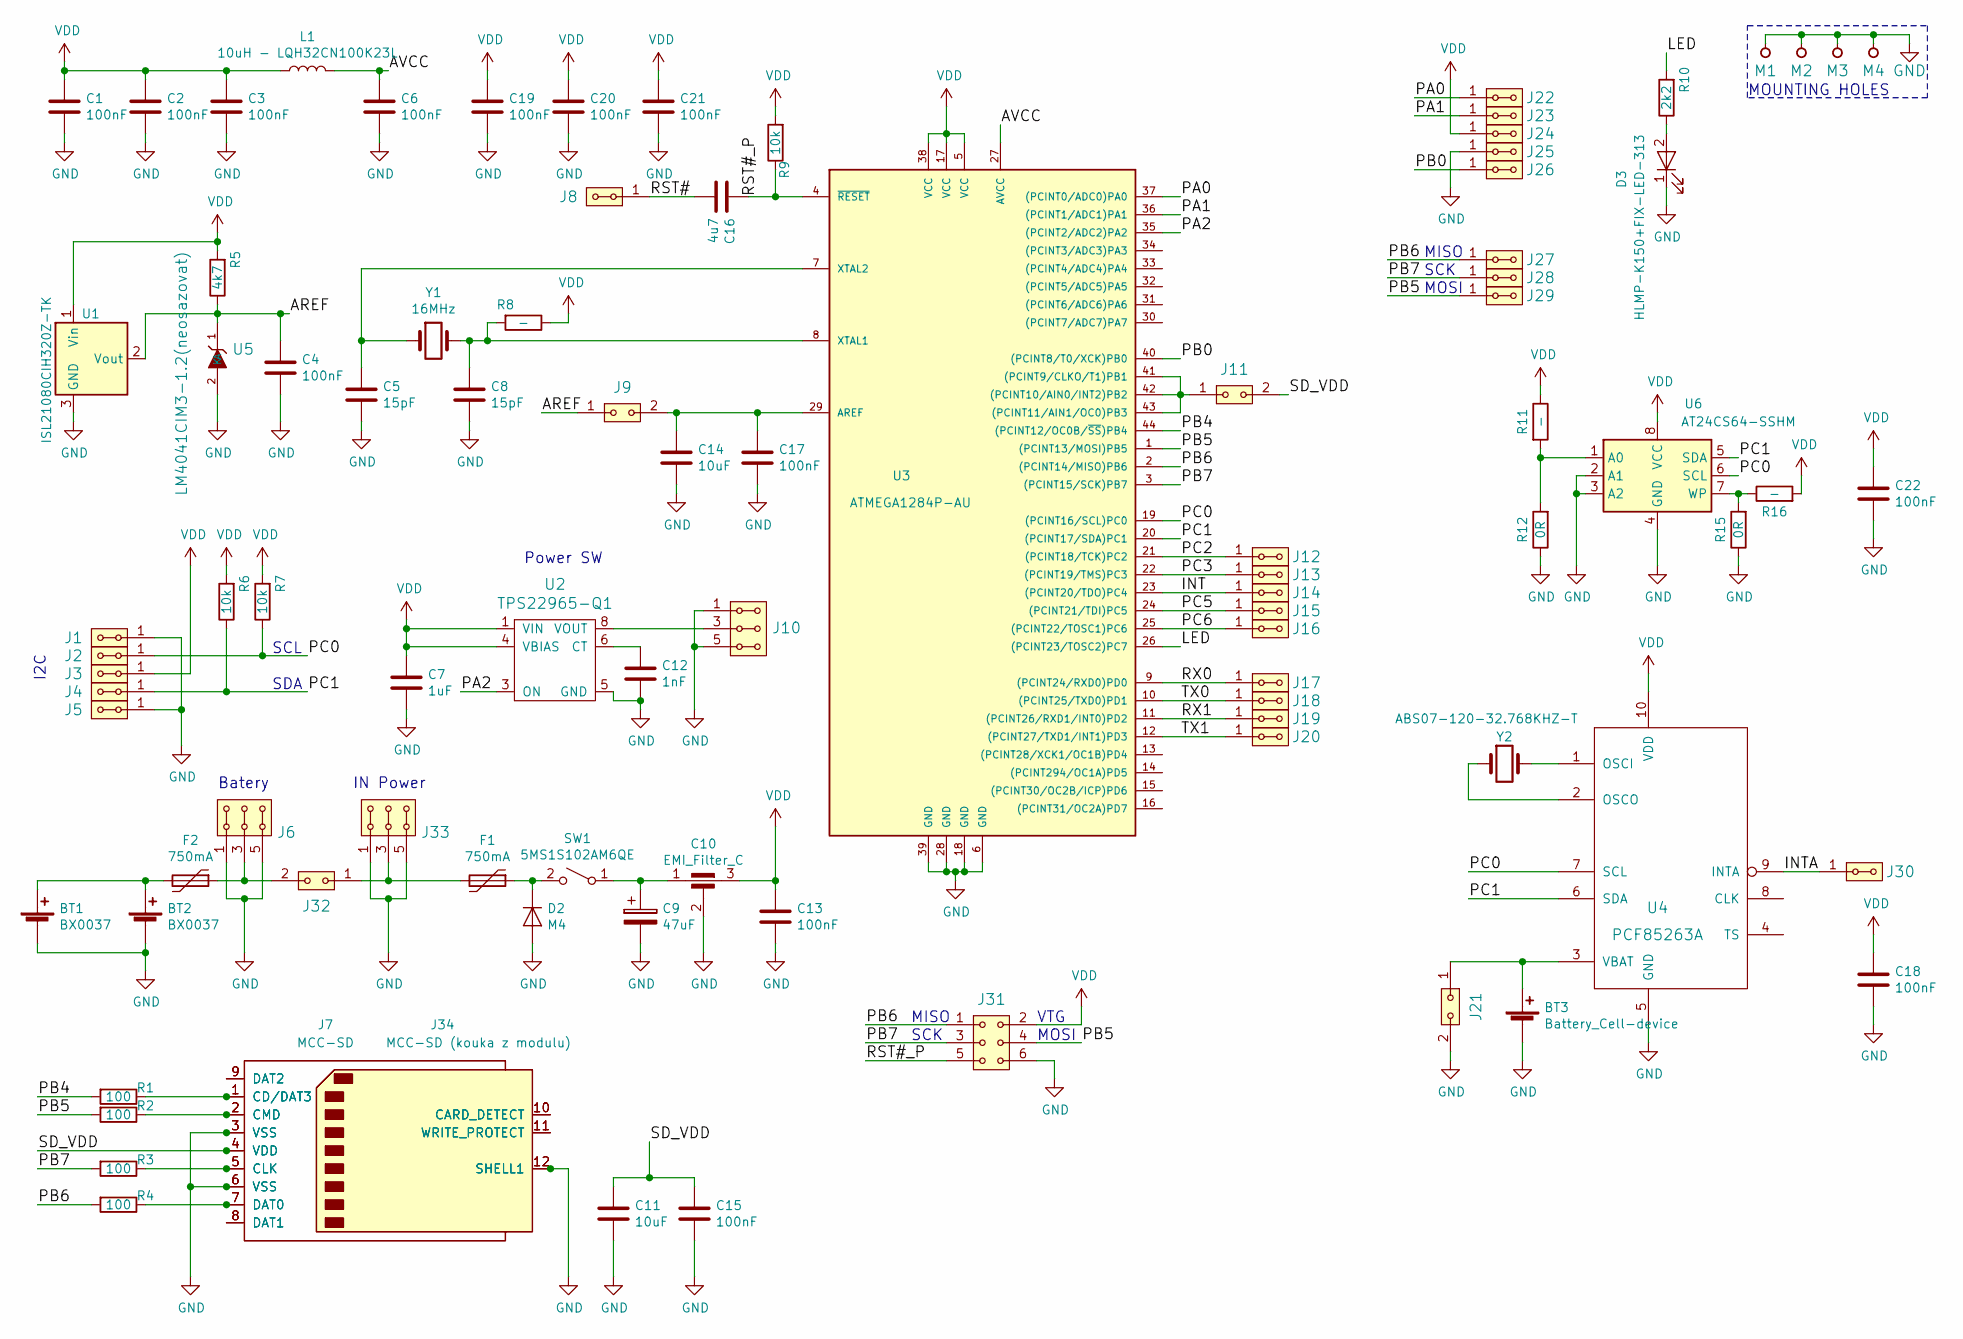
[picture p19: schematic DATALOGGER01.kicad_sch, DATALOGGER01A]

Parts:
BT1, BT2: BX0037
BT3: Battery_Cell-device; CH28-2032
C1, C2, C3, C4, C6, C13, C15, C17, C18, C19, C20, C21, C22: 100nF; SMD-0805
C5, C8: 15pF; SMD-0805
C7: 1uF; SMD-0805
C9: 47uF; TantalC_SizeC_Reflow
C10: EMI_Filter_C; FIR1
C11, C14: 10uF; SMD-0805
C12: 1nF; SMD-0805
C16: 4u7; SMD-0805
D2: M4; SMA_Standard
D3: HLMP-K150+FIX-LED-313; FIX-LED-313
F1, F2: 750mA; 1812
J1, J2, J3, J4, J5, J8, J12, J13, J14, J15, J16, J17, J18, J19, J20, J22, J23, J24, J25, J26, J27, J28, J29, J30: HEADER_2x01_PARALLEL; Straight_2x01
J6, J10, J33: HEADER_2x03_PARALLEL; Straight_2x03
J7: MCC-SD; SD_TE_2041021
J9, J11, J21, J32: HEADER_2x01; Straight_2x01
J31: HEADER_2x03; Straight_2x03
J34: MCC-SD (kouka z modulu); MCC-SD
L1: 10uH - LQH32CN100K23L; SMD-1210
M1, M2, M3, M4: HOLE; MountingHole_3mm
R1, R2, R3, R4: 100; SMD-0805
R5: 4k7; SMD-0805
R6, R7, R9: 10k; SMD-0805
R8, R11, R16: -; SMD-0805
R10: 2k2; SMD-0805
R12, R15: 0R; SMD-0805
SW1: 5MS1S102AM6QE
U1: ISL21080CIH320Z-TK; SOT-23
U2: TPS22965-Q1; WSON-8-1EP_2x2mm_P0.5mm_EP0.9x1.6mm_ThermalVias
U3: ATMEGA1284P-AU; TQFP-44_10x10mm_P0.8mm
U4: PCF85263A; TSSOP-10_3x3mm_Pitch0.5mm
U5: LM4041CIM3-1.2(neosazovat); SOT-23
U6: AT24CS64-SSHM; SOIC-8_3.9x4.9mm_P1.27mm
Y1: 16MHz; Crystal_HC49-U_Vertical
Y2: ABS07-120-32.768KHZ-T; ABS07

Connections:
/AREF: C4.1, J9.1, R5.1, U1.2 (Vout), U5.1 (K)
/AVCC: C6.1, L1.2, U3.27 (AVCC)
/INT: J14.1, J14.2, U3.23 ((PCINT20/TDO)PC4)
/INTA: J30.1, J30.2, U4.9 (INTA)
/LED: R10.2, U3.26 ((PCINT23/TOSC2)PC7)
/PA0: J22.1, J22.2, U3.37 ((PCINT0/ADC0)PA0)
/PA1: J23.1, J23.2, U3.36 ((PCINT1/ADC1)PA1)
/PA2: U2.3 (ON), U3.35 ((PCINT2/ADC2)PA2)
/PB0: J26.1, J26.2, U3.40 ((PCINT8/T0/XCK)PB0)
/PB4: R1.2, U3.44 ((PCINT12/OC0B/~SS)PB4)
/PB5: J29.1, J29.2, J31.4, R2.2, U3.1 ((PCINT13/MOSI)PB5)
/PB6: J27.1, J27.2, J31.1, R4.2, U3.2 ((PCINT14/MISO)PB6)
/PB7: J28.1, J28.2, J31.3, R3.2, U3.3 ((PCINT15/SCK)PB7)
/PC0: J2.1, J2.2, R7.1, U3.19 ((PCINT16/SCL)PC0), U4.7 (SCL), U6.6 (SCL)
/PC1: J4.1, J4.2, R6.1, U3.20 ((PCINT17/SDA)PC1), U4.6 (SDA), U6.5 (SDA)
/PC2: J12.1, J12.2, U3.21 ((PCINT18/TCK)PC2)
/PC3: J13.1, J13.2, U3.22 ((PCINT19/TMS)PC3)
/PC5: J15.1, J15.2, U3.24 ((PCINT21/TDI)PC5)
/PC6: J16.1, J16.2, U3.25 ((PCINT22/TOSC1)PC6)
/RST#: C16.2, J8.1, J8.2
/RST#_P: C16.1, J31.5, R9.1, U3.4 (~RESET)
/RX0: J17.1, J17.2, U3.9 ((PCINT24/RXD0)PD0)
/RX1: J19.1, J19.2, U3.11 ((PCINT26/RXD1/INT0)PD2)
/SD_VDD: C11.1, C15.1, J7.4 (VDD), J11.2, J34.4 (VDD)
/TX0: J18.1, J18.2, U3.10 ((PCINT25/TXD0)PD1)
/TX1: J20.1, J20.2, U3.12 ((PCINT27/TXD1/INT1)PD3)
GND: BT1.2 (-), BT2.2 (-), BT3.2 (-), C1.2, C2.2, C3.2, C4.2, C5.2, C6.2, C7.2, C8.2, C9.2, C10.2, C11.2, C12.2, C13.2, C14.2, C15.2, C17.2, C18.2, C19.2, C20.2, C21.2, C22.2, D2.2 (A), D3.1 (K), J1.1, J1.2, J5.1, J5.2, J6.1, J6.2, J6.5, J6.6, J7.3 (VSS), J7.6 (VSS), J7.12 (SHELL1), J10.1, J10.2, J10.5, J10.6, J21.2, J25.1, J25.2, J31.6, J33.1, J33.2, J33.5, J33.6, J34.3 (VSS), J34.6 (VSS), J34.12 (SHELL1), M1.1, M2.1, M3.1, M4.1, R12.1, R15.1, U1.3 (GND), U2.5 (GND), U2.9, U3.6 (GND), U3.18 (GND), U3.28 (GND), U3.39 (GND), U4.5 (GND), U5.2 (A), U6.2 (A1), U6.3 (A2), U6.4 (GND)
unnamed: BT1.1 (+), BT2.1 (+), F2.2
unnamed: BT3.1 (+), J21.1, U4.3 (VBAT)
unnamed: C5.1, U3.7 (XTAL2), Y1.1
unnamed: C8.1, R8.2, U3.8 (XTAL1), Y1.2
unnamed: C9.1, C10.1, SW1.1 (A)
unnamed: C12.1, U2.6 (CT)
unnamed: C14.1, C17.1, J9.2, U3.29 (AREF)
unnamed: D2.1 (K), F1.1, SW1.2 (B)
unnamed: D3.2 (A), R10.1
unnamed: F1.2, J32.1, J33.3, J33.4
unnamed: F2.1, J6.3, J6.4, J32.2
unnamed: J10.3, J10.4, U2.7 (VOUT), U2.8 (VOUT)
unnamed: J11.1, U3.41 ((PCINT9/CLKO/T1)PB1), U3.42 ((PCINT10/AIN0/INT2)PB2), U3.43 ((PCINT11/AIN1/OC0)PB3)
unnamed: J7.1 (CD/DAT3), J34.1 (CD/DAT3), R1.1
unnamed: J7.2 (CMD), J34.2 (CMD), R2.1
unnamed: J7.5 (CLK), J34.5 (CLK), R3.1
unnamed: J7.7 (DAT0), J34.7 (DAT0), R4.1
unnamed: J7.8 (DAT1), J34.8 (DAT1)
unnamed: J7.9 (DAT2), J34.9 (DAT2)
unnamed: J7.10 (CARD_DETECT), J34.10 (CARD_DETECT)
unnamed: J7.11 (WRITE_PROTECT), J34.11 (WRITE_PROTECT)
unnamed: R11.2, R12.2, U6.1 (A0)
unnamed: R15.2, R16.1, U6.7 (WP)
unnamed: U4.1 (OSCI), Y2.2
unnamed: U4.2 (OSCO), Y2.1
VDD: C1.1, C2.1, C3.1, C7.1, C10.3, C13.1, C18.1, C19.1, C20.1, C21.1, C22.1, J3.1, J3.2, J24.1, J24.2, J31.2, L1.1, R5.2, R6.2, R7.2, R8.1, R9.2, R11.1, R16.2, U1.1 (Vin), U2.1 (VIN), U2.2 (VIN), U2.4 (VBIAS), U3.5 (VCC), U3.17 (VCC), U3.38 (VCC), U4.10 (VDD), U6.8 (VCC)

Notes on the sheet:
MISO
VTG
SCK
Batery
I2C
IN Power
MOSI
Power SW
SDA
MOUNTING HOLES
SCL

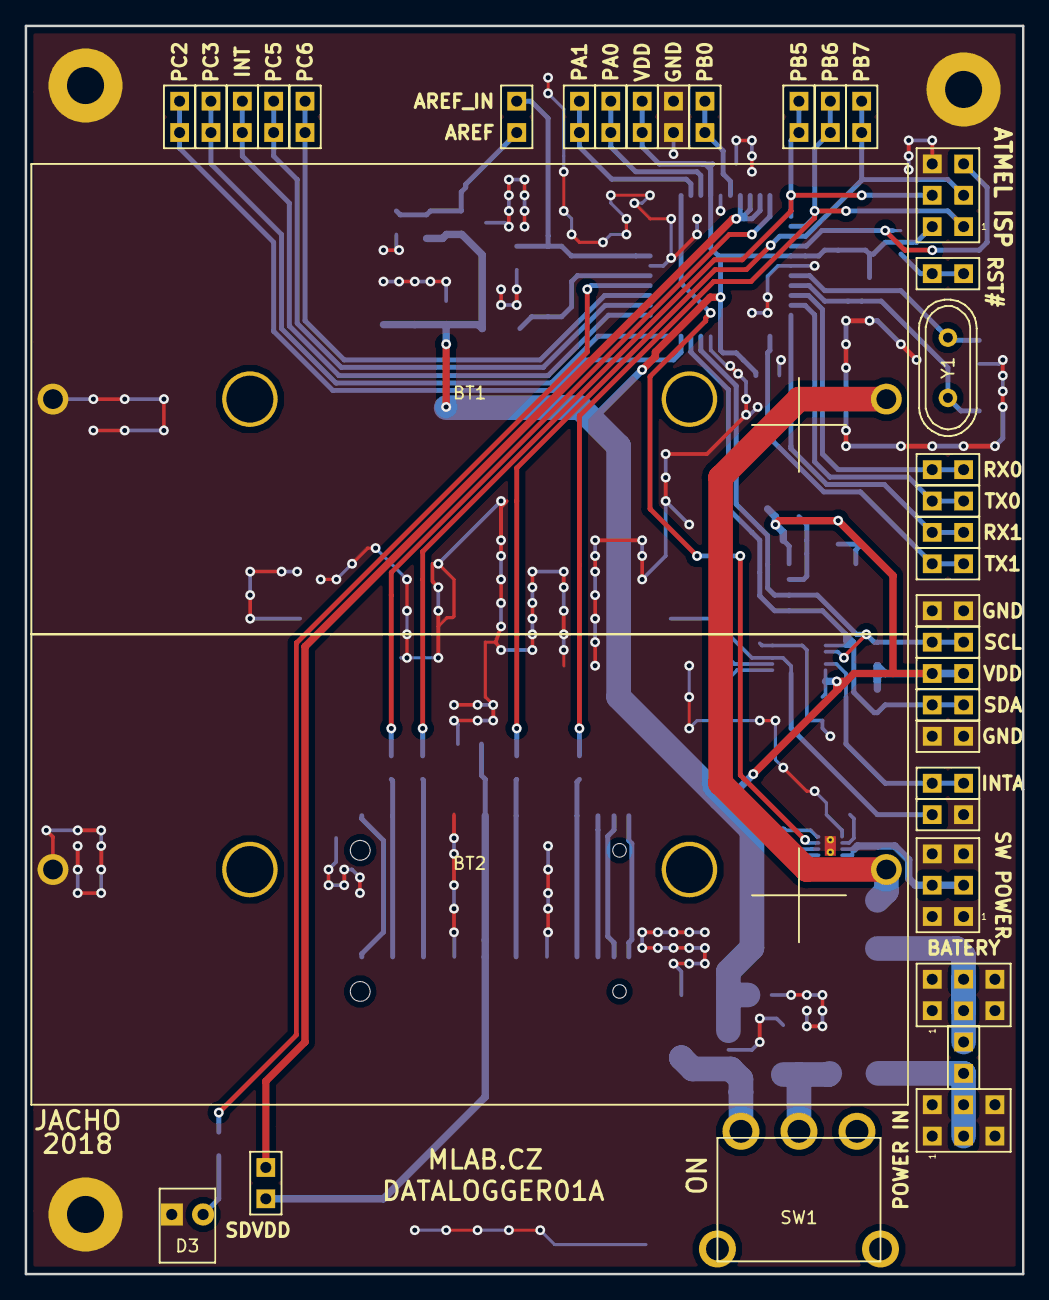
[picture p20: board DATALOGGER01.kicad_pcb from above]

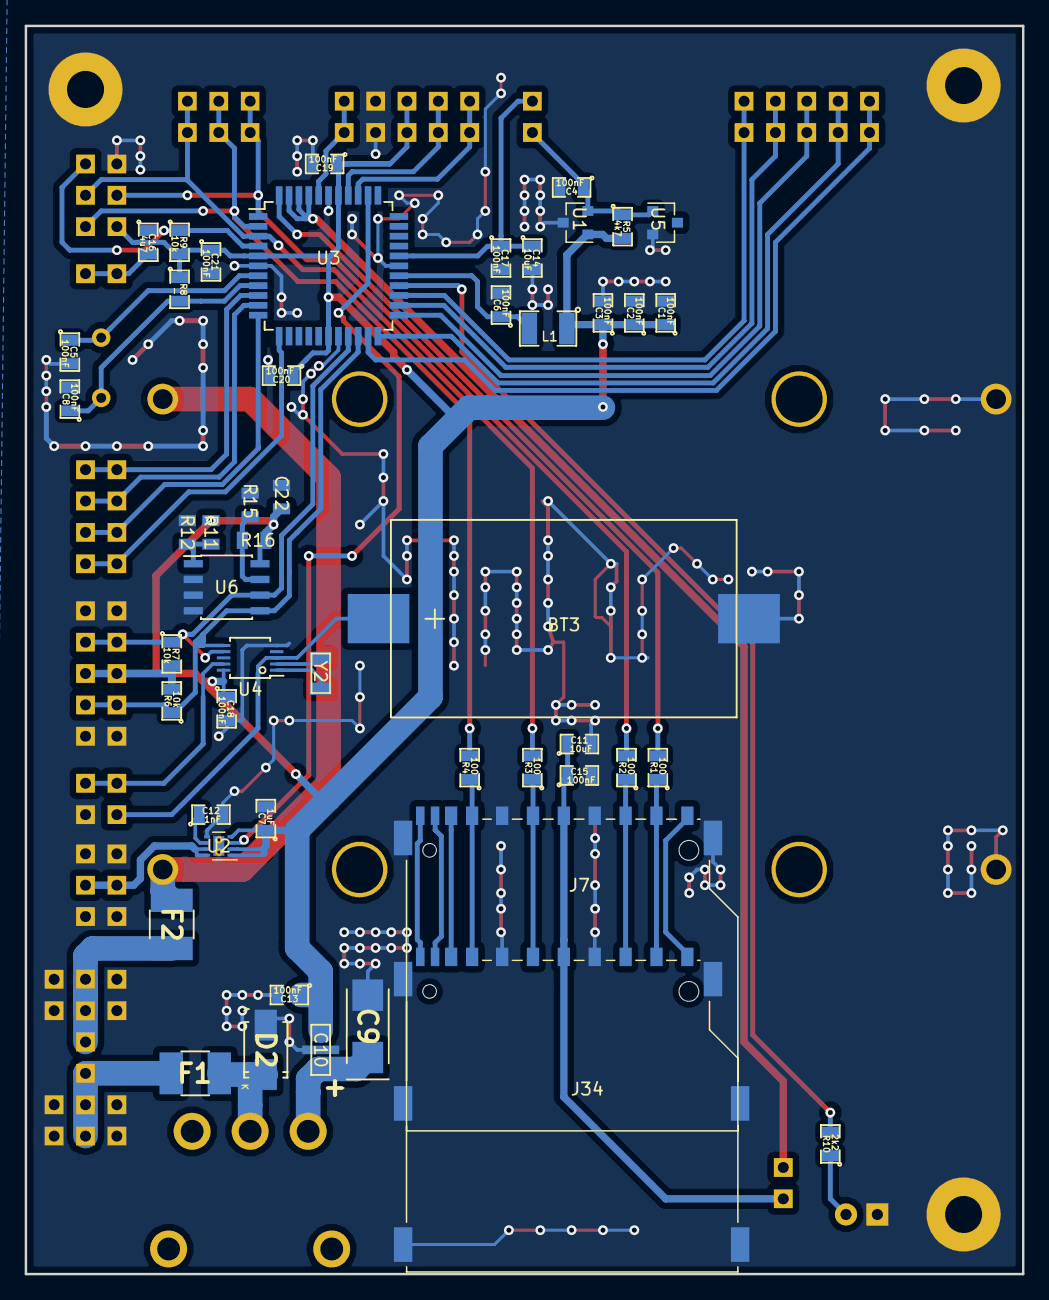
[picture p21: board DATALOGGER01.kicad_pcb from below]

Board: 2 copper layers, 80.8 x 101.1 mm, 90 parts (50 on the bottom side), 53 nets.

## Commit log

2018-06-06 [MLABweb] Documentaion edits; DATALOGGER01A
    [DATALOGGER01A.kicad_pcb, DATALOGGER01A.sch]
2018-06-06 Schema noveho modulu
    [DATALOGGER01A.sch, DATALOGGER01A_power.sch]
2018-06-08 Edit schema
    [DATALOGGER01A.sch, DATALOGGER01A_RTC.sch, DATALOGGER01A_power.sch]
2018-06-13 Editace schema
    [DATALOGGER01A.sch, DATALOGGER01A_power.sch]
2018-08-01 Pridani obvodu pro SSN. Oprava resetu.
    [DATALOGGER01A.kicad_pcb, DATALOGGER01A.sch]
2020-10-28 Fix licence and repository cleanup.
    [DATALOGGER01A.kicad_pcb, DATALOGGER01A.kicad_sch, DATALOGGER01A.sch]
2020-10-28 Documentation improvement. KiCAD files upgraded to new version.
2021-02-24 Doplneni soucastek na osazovani
    [DATALOGGER01A.kicad_sch]
2021-02-24 Doplnění součástek pro osazení
    [DATALOGGER01A.kicad_sch]
2021-08-27 Edit SCH
    [DATALOGGER01A.kicad_sch]
2021-12-29 Update schematics and title block.
    [DATALOGGER01A.kicad_pcb, DATALOGGER01A.kicad_sch]
2022-04-06 Update actions products
    [DATALOGGER01A-B_Adhesive.dxf, DATALOGGER01A-B_Courtyard.dxf, DATALOGGER01A-B_Cu.dxf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]
2022-08-14 Fix titleblock version.
    [DATALOGGER01A.kicad_sch]
2022-08-19 Update title blocks Place board to the center of page.
    [DATALOGGER01A.kicad_pcb, DATALOGGER01A.kicad_sch]
2022-08-19 Set up coordinates origin in left bottom corner of board.
    [DATALOGGER01A.kicad_pcb]
2023-07-05 automated commit; rename source files to new naming convence
    [DATALOGGER01.kicad_pcb, DATALOGGER01.kicad_sch]

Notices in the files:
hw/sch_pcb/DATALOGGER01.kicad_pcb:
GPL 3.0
